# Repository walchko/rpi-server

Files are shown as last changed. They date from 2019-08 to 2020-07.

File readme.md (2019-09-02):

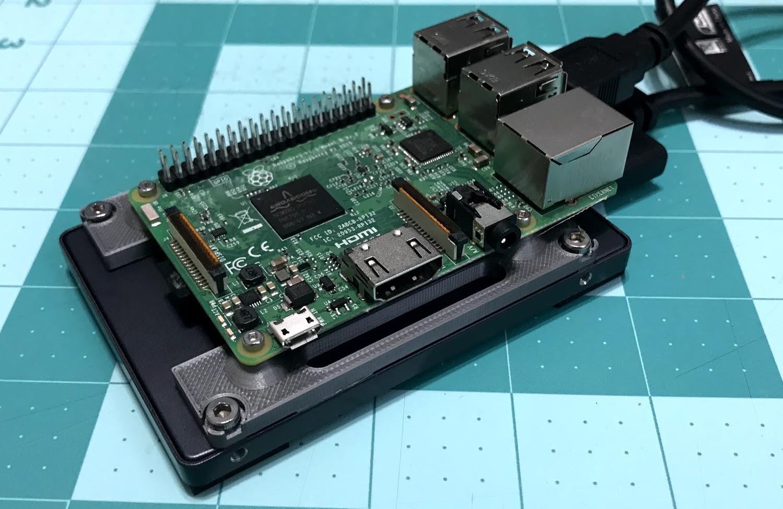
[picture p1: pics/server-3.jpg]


# Raspberry Pi Server

## Hardware

The design uses [openscad](www.openscad.org) for the design of the bracket.
You can use any slicer to generate gcode and print the bracket

- 3d printer and any color PLA
- M2-0.5 x 8mm screws and nuts for the raspberry pi
    - to get the nuts in the cut out, you can use the pull through method, since
    they are sized as a press fit (meaning very tight). I used a 12mm screw
    to pull the nuts through
- M3-0.5 x 6mm screws for the hard drive
- raspberry pi, hard drive, USB-to-SATA adaptor
    - I use a Startech cable I got from Amazon
    - I use an SSD because it is low power, a spinning disk might cause brown outs for you pi
- [PiOLED 128x32 display](https://www.adafruit.com/product/3527)
    - This is not necessary, but it is nice to display server name/address/performance
    - `sudo i2cdetect -y 1` should show the display at `0x3C`

## Software

There is nothing here you really need

- [mote](https://github.com/MomsFriendlyRobotCompany/mote) for setting up the
command line, web server (node), and file sharing (samba)
- PiOLED is in the software folder
- [Plex](https://www.plex.tv/) maintains a version for Raspberry Pi, so you can serve up movies

## Changes

- **Version 4**
    - Using all metric M2 and M3 screws now
    - Cut out the front so you can get to the SD card easier
    - Embedded nuts in the design, so they aren't sticking up on the top
    - Updated the LCD script
        - Linux release name
        - Added kernel version
        - Heartbeat is only 1 character now
- **Version 3**
    - Raised the pi up higher on the pillars
    - Centered the pi in the middle of the bracket
    - Skeletonize the design so it doesn't use so much plastic
- **Version 2**
    - Added a script for Adafruit's LCD

## ToDo

- I want to do an optional cover to protect the pi
    - Maybe a fan?
    - Maybe mount the LCD (or another one) differently
    - Might be better to have it plexiglass instead of PLA?

# Hardware (STL): Createive Commons-Attribution-ShareAlike

# Software (OpenSCAD): MIT License

**Copyright (c) 2018 Kevin Walchko**

Permission is hereby granted, free of charge, to any person obtaining a copy
of this software and associated documentation files (the "Software"), to deal
in the Software without restriction, including without limitation the rights
to use, copy, modify, merge, publish, distribute, sublicense, and/or sell
copies of the Software, and to permit persons to whom the Software is
furnished to do so, subject to the following conditions:

The above copyright notice and this permission notice shall be included in all
copies or substantial portions of the Software.

THE SOFTWARE IS PROVIDED "AS IS", WITHOUT WARRANTY OF ANY KIND, EXPRESS OR
IMPLIED, INCLUDING BUT NOT LIMITED TO THE WARRANTIES OF MERCHANTABILITY,
FITNESS FOR A PARTICULAR PURPOSE AND NONINFRINGEMENT. IN NO EVENT SHALL THE
AUTHORS OR COPYRIGHT HOLDERS BE LIABLE FOR ANY CLAIM, DAMAGES OR OTHER
LIABILITY, WHETHER IN AN ACTION OF CONTRACT, TORT OR OTHERWISE, ARISING FROM,
OUT OF OR IN CONNECTION WITH THE SOFTWARE OR THE USE OR OTHER DEALINGS IN THE
SOFTWARE.

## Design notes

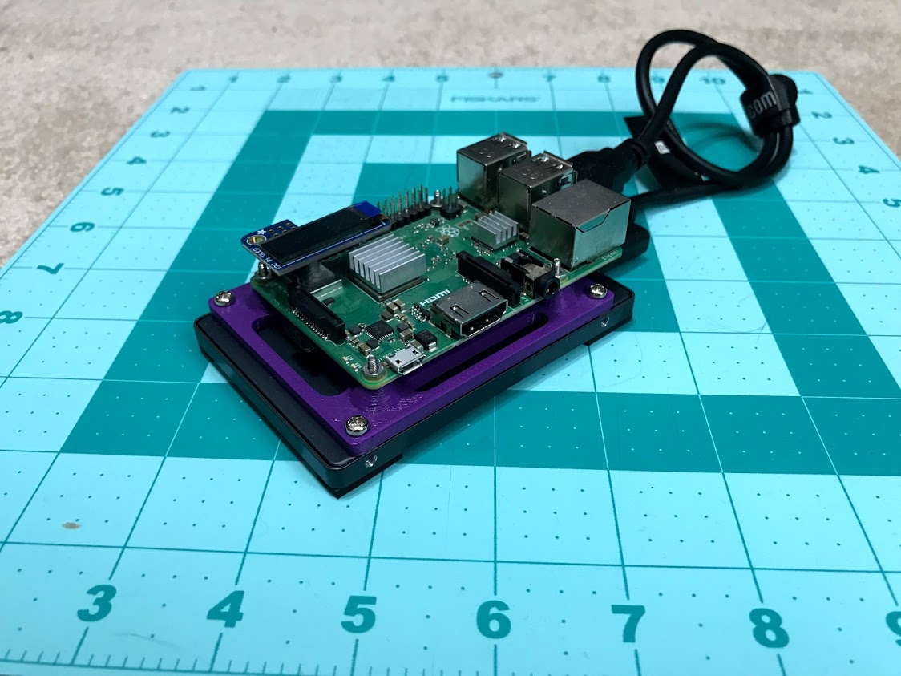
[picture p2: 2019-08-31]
pics/server-v3.jpg

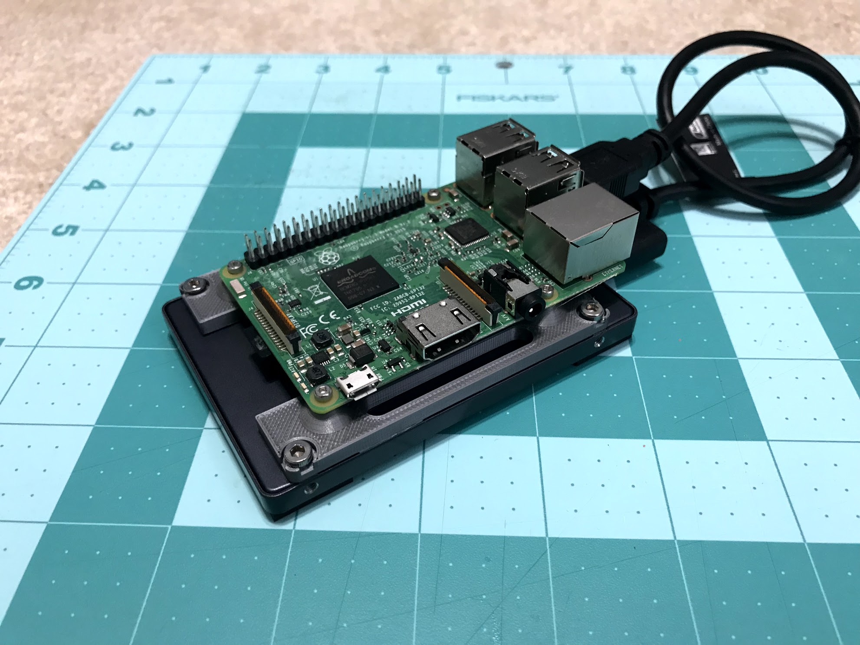
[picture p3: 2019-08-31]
pics/server-v4.jpg

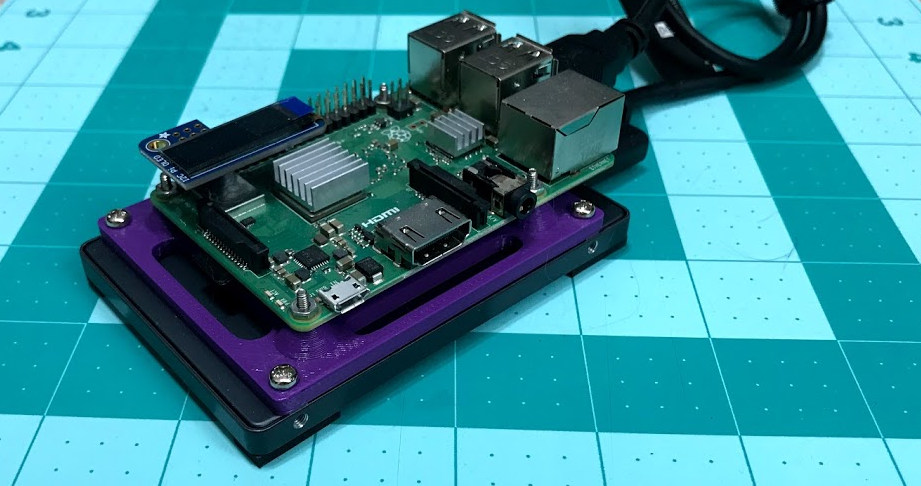
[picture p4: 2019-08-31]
pics/server-2.png

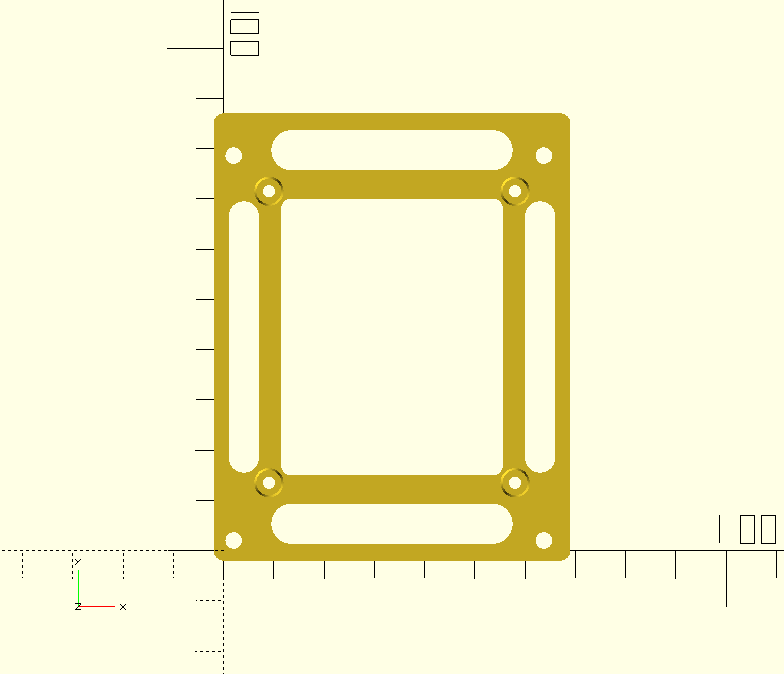
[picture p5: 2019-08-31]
openscad/server.png

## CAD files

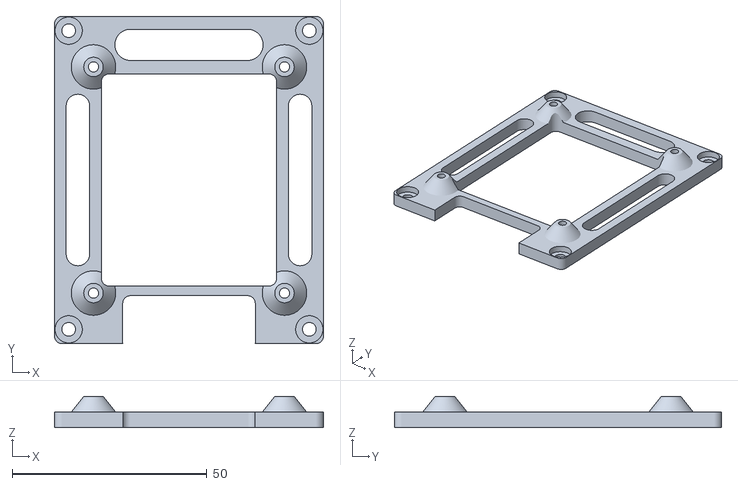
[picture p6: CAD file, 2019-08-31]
openscad/server-v4.stl
69.0 x 84.0 x 8.00

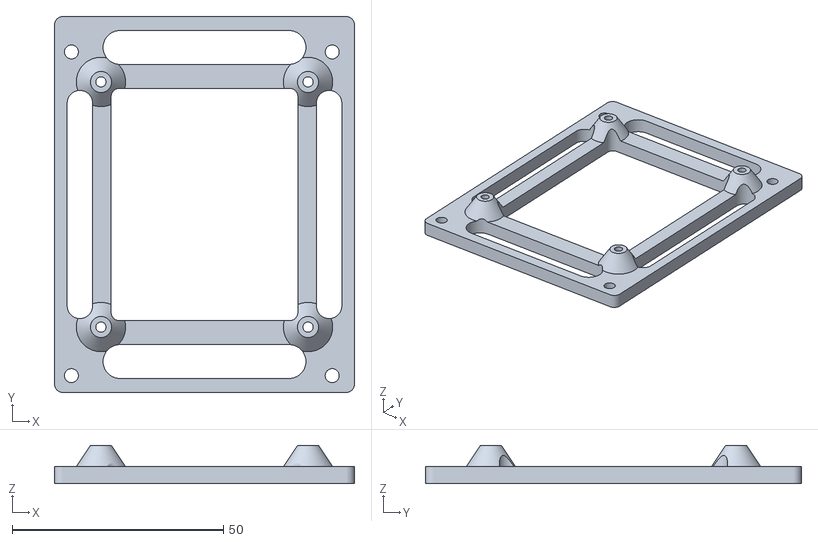
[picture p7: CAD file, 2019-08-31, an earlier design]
openscad/server.stl
71.0 x 89.0 x 9.00

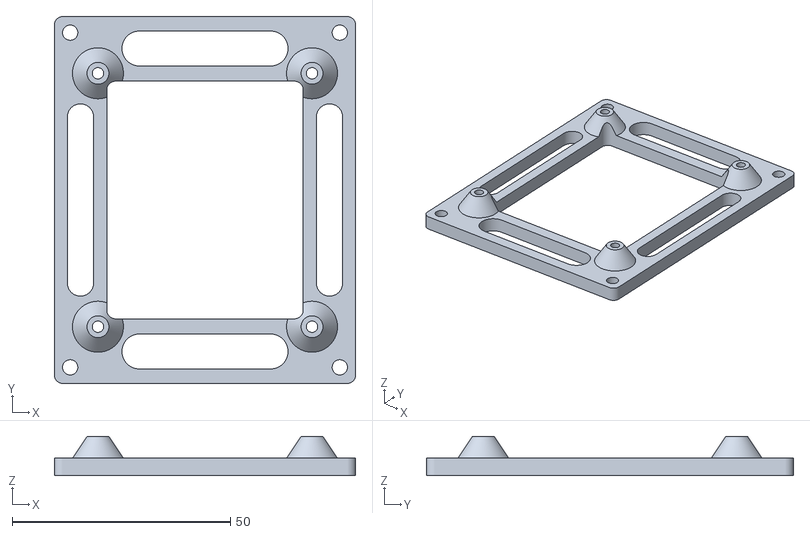
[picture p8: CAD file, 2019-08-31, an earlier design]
openscad/server-v3.stl
69.0 x 84.0 x 9.00

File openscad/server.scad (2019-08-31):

// MIT License 2018 Kevin J. Walchko

$fn=90;

/* use <lib/pi.scad>; */

module hex(side,t){
    intersection(){
        cube([side, side, 1.5*t],center=true);
        rotate([0,0,45]) cube([side, side, 1.5*t], center=true);
    }
}

module M3(){
    cylinder(h=40, d=3.5, center=true);
    translate([0,0,2]) cylinder(h=6, d=7, center=false);
}

module M2(){
    cylinder(h=40, d=2.6, center=false);
}

module base(width, length, thick, dia){
    linear_extrude(height=thick) hull(){
        circle(d=dia);
        translate([width,0,0]) circle(d=dia);
        translate([width,length,0]) circle(d=dia);
        translate([0,length,0]) circle(d=dia);
    }
}

module hcut(dia, length){
    // along x-axis
    translate([0,0,-5]) linear_extrude(height=15) hull(){
        circle(d=dia);
        translate([length,0,0]) circle(d=dia);
    }
}

module vcut(dia, length){
    // along y-axis
    translate([0,0,-5]) linear_extrude(height=15) hull(){
        circle(d=dia);
        translate([0,length,0]) circle(d=dia);
    }
}

module plate(width, length, thick=3){
    dia = 4;
    scale = 0.63;
    xbase = (width - 49)/2;
    ybase = (length-58)/2;

    dx = (1-scale)*width/2;
    dy = (1-scale)*length/2;
    difference()
    {
        union(){
            base(width, length, thick, dia);
            // stand-offs
            translate([xbase, ybase, thick-1]){
                sd1 = 13;
                sd2 = 5;
                up = 5;
                translate([0,0,0]) cylinder(h=up, d1=sd1,d2=sd2);
                translate([49,0,0]) cylinder(h=up, d1=sd1, d2=sd2);
                translate([49,58,0]) cylinder(h=up, d1=sd1, d2=sd2);
                translate([0,58,0]) cylinder(h=up, d1=sd1, d2=sd2);
            }
        }

        // center cut
        translate([dx,dy,-thick/2]) base(scale*width, scale*length, thick*5, dia);

        // HD mounting holes
        hdw = 61.72;
        hdl = 76.6;
        hdx = (width - hdw)/2;
        hdy = (length - hdl)/2;
        translate([hdx,hdy,0]){
            translate([0,0,0]) M3();
            translate([hdw,0,0]) M3();
            translate([hdw,hdl,0]) M3();
            translate([0,hdl,0]) M3();
        }

        // pi mounting holes
        translate([xbase, ybase, 0]){
            translate([0,0,0]) M2();
            translate([49,0,0]) M2();
            translate([49,58,0]) M2();
            translate([0,58,0]) M2();
        }

        // horizontal cuts - along x-axis
        cw = 30;
        cd = 8;
        /* translate([(width-cw)/2,cd/1.5,0]) hcut(cd, cw);
        translate([(width-cw)/2,cd/1.5-5,0]) hcut(cd, cw); */
        translate([(width-cw)/2,cd/1.5-7,-1]) base(30, 10, thick*5, dia);
        translate([(width-cw)/2,length-cd/1.5,0]) hcut(cd, cw);

        // vertical cuts - along y-axis
        cl = 38;
        cld = 6;
        translate([cld/1.5,(length-cl)/2,0]) vcut(cld, cl);
        translate([width-cld/1.5,(length-cl)/2,0]) vcut(cld, cl);

        // nut cutouts
        translate([xbase, ybase, -1]){
            side = 4.1;
            t = 7;
            /* translate([0,0,0]) cylinder(h=up, d=sdia); */
            translate([0,0,0]) hex(side, t);
            translate([49,0,0]) hex(side, t);
            translate([49,58,0]) hex(side, t);
            translate([0,58,0]) hex(side, t);
        }
    }

    /* translate([xbase, ybase, 0]){
        dia = 7;
        up = 6;
        translate([0,0,0]) cylinder(h=up, d=dia);
        translate([49,0,0]) cylinder(h=up, d=dia);
        translate([49,58,0]) cylinder(h=up, d=dia);
        translate([0,58,0]) cylinder(h=up, d=dia);
    } */

    /* cl = 40;
    cd = 6;
    translate([cd/2,(length-cl)/2,0]) vcut(cd, cl);
    translate([width-cd/2,(length-cl)/2,0]) vcut(cd, cl); */

}

width = 65;
height = 80;
thickness = 4;
plate(width, height, thickness);

/* translate([49/2,58/2, 10]) rotate([0,0,-90]) rpi3(); */

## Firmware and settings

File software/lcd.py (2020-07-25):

#!/usr/bin/env python3
# MIT License 2018 Kevin J. Walchko

# This is run using the system python, so just use python3
# make sure to install:
# pip install -U Adafruit-SSD1306 pillow netifaces psutil

import netifaces as nf
import psutil as ps
import socket
import time
# import Adafruit_GPIO.SPI as SPI
# import Adafruit_SSD1306
import os

from PIL import Image
from PIL import ImageFont
from PIL import ImageDraw

from board import SCL, SDA
import busio
import adafruit_ssd1306

# start ---
i2c = busio.I2C(SCL, SDA)
# disp = Adafruit_SSD1306.SSD1306_128_32(rst=24)
disp = adafruit_ssd1306.SSD1306_I2C(128, 32, i2c)
# disp.begin()

# Get display width and height.
width = disp.width
height = disp.height

# clear display ----
# disp.clear()
# disp.display()

# setup ---
# Create image buffer.
# Make sure to create image with mode '1' for 1-bit color.
image = Image.new('1', (width, height))

# Get drawing object to draw on image.
draw = ImageDraw.Draw(image)

# Draw a black filled box to clear the image.
draw.rectangle((0,0,width,height), outline=0, fill=0)

# Load default font.
font = ImageFont.load_default()

# https://github.com/sindresorhus/cli-spinners/blob/HEAD/spinners.json
# spin = ['|','/','--','\\','+']
spin = ['.','o','O','0','O','o']
wrap = len(spin)
i = 0
x = 0
top = -2

def getRelease():
    with open("/etc/os-release") as fd:
        d = fd.read()
    m = {}
    # print(d)
    d = d.split('\n')
    for s in d:
        # print(">>", s)
        try:
            k,v = s.split('=')
            # print(k,'\n',v)
            m[k] = v
        except Exception as e:
            # print(e)
            continue
    # print(m)
    return m


try:
    # get release name: buster
    relinfo = getRelease()
    rel = relinfo["VERSION_CODENAME"]
    # get linux kernel version: 4.23
    ver = os.uname().release.split('-')[0]
    ver = '.'.join(ver.split('.')[:2])
    while True:
        draw.rectangle((0,0,width,height), outline=0, fill=0)

        # get interfaces
        ifs = nf.interfaces()
        # ap = False
        # if 'wlan1' in ifs:
        #    addr = nf.ifaddresses('wlan0')[nf.AF_INET][0]['addr']
        #    if addr == '10.10.10.1':
        #        ap = True
        addrs = []
        for ip in ['en0', 'eth0', 'wlan0']:
            if ip in ifs:
                addr = nf.ifaddresses(ip)[nf.AF_INET][0]['addr']
                addrs.append((ip, addr,))

        # print heartbeat, name, release, kernel version
        str = "{} {} {} {}".format(
            spin[i%wrap],
            socket.gethostname().split('.')[0],
            rel,
            ver
        )

        i += 1
        draw.text((x,top), str, font=font, fill=127)

        # get cpu and memory performance
        cpu = ps.cpu_percent()
        mem = ps.virtual_memory().percent
        str = "CPU: {:3.0f}% Mem: {:3.0f}%".format(cpu,mem)
        draw.text((x,top+8), str, font=font, fill=255)

        # get networking for ethernet and wifi
        for cnt, (ip, addr) in enumerate(addrs):
            str = "{}: {}".format(ip, addr)
            draw.text((x,top+8+(cnt+1)*8), str, font=font, fill=255)

        disp.image(image);
        disp.show()
        time.sleep(1)
except KeyboardInterrupt:
    print('bye ...')

# clear display ----
# disp.clear()
# disp.display()
# Draw a black filled box to clear the image.
draw.rectangle((0,0,width,height), outline=0, fill=0)
disp.image(image);
disp.show()
time.sleep(0.1)

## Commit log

2019-08-31 happy with lcd program :tada: :bento:
    [lcd.py]
2020-07-25 :bento: working latest adafruit library :tada:
    [lcd.py]
